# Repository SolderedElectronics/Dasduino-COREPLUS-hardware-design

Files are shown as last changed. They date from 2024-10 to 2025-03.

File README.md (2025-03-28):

# Dasduino COREPLUS Hardware Design

## About the Product

| Dasduino COREPLUS Image |
| :----------------------------------------------------------: |
| [Buy Dasduino COREPLUS](https://www.solde.red/333268) |

The soldered version of the ATmega2560 microcontroller board has arrived! It is designed for enthusiasts and professionals in the field of electronics and DIY projects. The heart of the board, the ATmega2560, is a powerful 8-bit microcontroller that offers enough processing power for demanding applications. The board comes with a large number of digital and analog inputs/outputs, allowing users to connect various sensors and actuators. The ATmega2560 contains a significant amount of Flash memory, SRAM, and EEPROM, which is sufficient for complex applications and data storage. The USB interface allows for easy programming and communication with a computer. It enables communication with various peripheral devices and modules using the qwiic system for simple connectivity. The board is compatible with popular development environments, such as Arduino IDE, which facilitates the development and implementation of projects.

This board is ideal for creating complex and versatile electronic projects, such as automatic systems, smart devices, robotics, and many others.

---

## Repository Contents

This repository contains all design files for Dasduino COREPLUS, organized as follows:

- **`CAD` folder**: Contains KiCAD design files, including:
  - Schematics
  - PCB layout
  - Panel PCB layout
  - Source 3D files in Fusion360, if any
  - All files are sorted by version with a detailed change log.
- **`OUTPUTS` folder**: Includes all production-ready files, such as:
  - Bill of Materials (BOM) and interactive BOM (iBOM)
  - PDF versions of schematics
  - 3D `.step` file of the board
  - 3D-printable models
  - Gerber files for PCB manufacturing
  - Image of the pinout of the board
  - Product image
  - Compliance, legal and generic sales documents

Refer to the `Change Log` in the CAD folder for details about updates between versions.

---

## Learn More About the Product

Beyond the repository, explore the following resources:

### Soldered Verify

Soldered Verify Logo

The **Soldered Verify** system ensures every board you purchase from Soldered is fully functional. It also provides access to exclusive test data for your product. To get started, find the unique Soldered Verify ID on your product's packaging and enter the ID on the [Soldered Verify page](https://soldered.com/verify/) to access test results and additional product details.

### Soldered Community

soldered-verify-logo

Soldered Community is your go-to place for technical support. Our engineers track and answer all questions posted there, and it’s a great space for the maker community. Get answers to your questions and solutions for your challenges at [Soldered Community](https://soldered.com/community).

### solde.red

solde.red is an ultimate URL shortener and information hub. Access it by typing solde.red/ followed by your product SKU, e.g., [solde.red/333000](https://solde.red/333000), to find getting-started guides, datasheets, open-source hardware and software files, certifications, images, pinouts, and more. Read more about the shortener [here](https://solde.red/info/).

---

## Contributing

Contributions are welcome! Here’s how you can get involved:

- Submit pull requests to enhance the design or fix issues.
- Report bugs or problems by opening an issue.

We encourage community collaboration to make this product even better.

---

## About Soldered

soldered-logo

[Soldered for Makers](https://soldered.com) specializes in designing and manufacturing electronic products tailored for enthusiasts, ranging from hobbyists to professionals. Our portfolio includes electronic boards, sensors, and actuators that are widely utilized in fields such as microelectronics, mechatronics, robotics, programming, and IoT. Every product we offer is designed in-house and built upon open-source hardware and software platforms. Proudly certified and manufactured within the European Union, our catalog likely includes the product you need for your project.

We complement these products with comprehensive tutorials and manuals, product descriptions, schematics, programming codes, and project examples. Our round-the-clock [customer and technical support](https://soldered.com/community) is available for all our products, irrespective of the sales channel. Soldered’s success and services reflect our maker community’s unwavering [trust](https://www.trustpilot.com/review/soldered.com), for which we are deeply grateful. Join our community and create using Soldered products.

---

## License

All Soldered open-source hardware (OSH) is under The TAPR Open Hardware License. Read more in the LICENSE file located in this repository.

**Disclaimer:**

No warranty - all designs in this repository are distributed in the hope that they will be useful, but without any warranty. They are provided "AS IS", therefore without warranty of any kind, either expressed or implied. The entire quality and performance of what you do with the contents of this repository are your responsibility. In no event Soldered Electronics will be liable for your damages, or losses, including any general, special, incidental, or consequential damage arising out of the use or inability to use the contents of this repository. 

---

## Have fun!

Thank you for your support from your fellow makers at Soldered Electronics.

Happy Making!

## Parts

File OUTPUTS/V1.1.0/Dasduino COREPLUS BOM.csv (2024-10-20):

Id | Designator | Package | Quantity | Designation | Supplier and ref
1 | JP6,JP5 | SMD_JUMPER_3_PAD_TRACE | 2 | SMD_JUMPER_3_PAD_TRACE
2 | R19,R10,R21,R20,R22 | 0603R | 5 | 10k
3 | R2,R1,R5 | 0603R | 3 | 1k
4 | R3,R17,R4,R12 | 0402R | 4 | 2k2
5 | F1 | 1206FUSE | 1 | 1206FUSE-500mA
6 | C26,C1,C24,C21,C25,C10,C22,C18,C23,C2,C19,C4,C11,C20 | 0603C | 14 | 100n
7 | U5 | SOT-363 | 1 | NMOS-DUAL
8 | JP4 | SMD_JUMPER | 1 | SMD_JUMPER
9 | C5,C3,C7,C9,C8 | 0603C | 5 | 2u2
10 | D2,D6 | 0402LED | 2 | orange
11 | JP2,JP3,JP1 | SMD-JUMPER-CONNECTED_TRACE_SOLDERMASK | 3 | SMD-JUMPER-CONNECTED_TRACE_SOLDERMASK
12 | C14,C15,C12,C13 | 1206C | 4 | 10u
13 | H3,H4,H1,H2 | HOLE_3.2mm | 4 | HOLE_3.2mm
14 | R7,R8 | 0603R | 2 | 5k1
15 | U2 | TPS7A2633DRVR | 1 | TPS7A2633DRVR
16 | R18 | 0603R | 1 | 100
17 | D4 | WS2812B-2020 | 1 | WS2812B-2020
18 | D3 | 0402LED | 1 | purple
19 | U4 | TQFP-100 | 1 | ATMEGA2560-16AU
20 | U1 | SOP-16 | 1 | CH340C
21 | K1 | easyC-connector | 1 | easyC-SMD
22 | K8 | HYC77-TF09-200 | 1 | HYC77-TF09-200
23 | D1 | 0402LED | 1 | blue
24 | R16,R14,R15,R13,R9 | 0603R | 5 | 100k
25 | Q1,Q2 | SOT-23-3 | 2 | PMOS
26 | C16,C17 | 0603C | 2 | 22p
27 | U6 | TXB0104QPWRQ1 | 1 | TXB0104QPWRQ1
28 | D5 | 0402LED | 1 | red
29 | SW1,SW2 | YTSA007A0151803B | 2 | YTSA007A0151803B
30 | C6 | 0603C | 1 | 270p
31 | K3 | JST-2pin-SMD | 1 | JST-2pin-SMD
32 | TP2,TP1 | Test_Point_SMD_0.8mm | 2 | Test_Point_SMD_0.8mm
33 | U3 | TP4056M-MSOP8 | 1 | TP4056M
34 | R11 | 0603R | 1 | 3k
35 | R6 | 0402R | 1 | 330
36 | D7 | SOD-323 | 1 | BAT20J
37 | X1 | CRYSTAL_3225__4_PAD | 1 | 16MHz
38 | K2 | U262-161N-4BVC11 | 1 | U262-161N-4BVC11
39 | K6 | HEADER_MALE_20x1 | 1 | HEADER_MALE_20X1
40 | K4,K5 | HEADER_MALE_40X1 | 2 | HEADER_MALE_40X1

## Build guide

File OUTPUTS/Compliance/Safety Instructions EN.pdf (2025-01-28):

PLEASE RETAIN THIS INFORMATION FOR FUTURE REFERENCE.

BEFORE USING THIS PRODUCT, READ ALL INSTRUCTION IN THIS DOCUMENT.

Product name: Dasduino COREPLUS (ATmega2560)
Getting started: To get started, please visit www.soldered.com

## WARNINGS

- This product should not be covered and should be operated in well ventilated enviroment.
- The product should be placed on a stable, flat, non-conductive surface and should not be contacted by conductive items.
- Connection of other devices may affect compliance or result in damage to the unit, and invalidate the warranty.
- Where peripherals are connected that do not include the cable or connector, the cable or connector used must offer adequate insulation and operation in order that the requirements of the relevant performance and safety requirements are met.
- There is a danger of explosion if the battery is incorrectly placed.
- The product should not be used outside of its specified working range.

## INSTRUCTIONS FOR SAFE USE

To avoid malfunction or damage to your device, please observe the following:
- Do not expose it to water, moisture or place on a conductive surface when turned on. Do not handle the unit with wet hands.
- Do not expose it to heat from any source; the product is designed to be used at normal ambient room temperatures. The product is intended to be used inside.
- Take care when handling to avoid mechanical or electrical damage to any part of the unit. Avoid handling the unit while it's powered. Use ESD protection.
- Use only supplied cable (or the cable of the same or higher quality) with the unit.

## COMPLIANCE INFORMATION

The product complies with the relevant provision of the RoHS Directive for the European Union. In common with all Electrical and Electronic Equipment (EEE), the product should not be disposed household waste.

ELECTROMAGNETIC COMPABILITY AND OPERATION

- The product is in conformity with the protection requirements of EU Council Directive 2014/30/EU on the laws of the Member States relating of electromagnetic compability, and Electromagnetic Compability Regulations 2016 of the UK.
- WARNING: Please do not alter the design of this product, doing so may void your ability to use the product freely, this includes altering the frequency at which product operates.

### Regulatory Compliance and Important Safety Information

Soldered Electronics d.o.o., Vinkovačka cesta 68, 31000 Osijek, Croatia. VAT ID: HR83200237288

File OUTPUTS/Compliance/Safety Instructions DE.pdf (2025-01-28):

BITTE BEWAHREN SIE DIESE INFORMATIONEN ZUR SPÄTEREN VERWENDUNG AUF.
LESEN SIE VOR DER VERWENDUNG DIESES PRODUKTS ALLE ANWEISUNGEN IN DOKUMENT. Produktname: Dasduino COREPLUS (ATmega2560)
Die ersten Schritte:Besuchen Sie www.soldered.com, um loszulegen.

## WARNUNGEN

- Dieses Produkt sollte nicht abgedeckt werden und in einer gut belüfteten Umgebung betrieben werden.
- Das Produkt sollte auf einer stabilen, flachen, nicht leitenden Oberfläche aufgestellt werden und nicht mit leitenden Gegenständen in Berührung kommen.
- Der Anschluss anderer Geräte kann die Konformität beeinträchtigen oder zu Schäden am Gerät führen und zum Erlöschen der Garantie führen.
- Wenn Peripheriegeräte angeschlossen werden, die nicht das Kabel oder den Stecker enthalten, muss das verwendete Kabel oder muss das verwendete Kabel bzw. der verwendete Steckverbinder eine angemessene Isolierung und Funktion aufweisen, damit die Anforderungen die einschlägigen Leistungs- und Sicherheitsanforderungen erfüllt werden.
- Es besteht Explosionsgefahr, wenn die Batterie falsch eingesetzt wird.
- Das Produkt sollte nicht außerhalb des angegebenen Arbeitsbereichs verwendet werden.

## HINWEISE ZUR SICHEREN ANWENDUNG

Um Fehlfunktionen oder Schäden an Ihrem Gerät zu vermeiden, beachten Sie bitte die folgenden Hinweise:
- Setzen Sie das Gerät nicht Wasser oder Feuchtigkeit aus und stellen Sie es nicht auf eine
leitende Oberfläche, wenn es eingeschaltet ist. Das Gerät nicht mit nassen Händen anfassen.
- Setzen Sie es keiner Wärmequelle aus; das Produkt ist für die Verwendung bei normalen Raumtemperaturen ausgelegt. Das Produkt ist für die Verwendung in Innenräumen vorgesehen.
- Seien Sie bei der Handhabung vorsichtig, um mechanische oder elektrische Schäden an Teilen des Geräts zu vermeiden. Fassen Sie das Gerät nicht an, wenn es unter Spannung steht. Verwenden Sie einen ESD-Schutz.
- Verwenden Sie nur das mitgelieferte Kabel (oder ein gleich- oder höherwertiges Kabel)
mit dem Gerät.

## COMPLIANCE-INFORMATIONEN

Das Produkt entspricht den entsprechenden Bestimmungen der RoHS-Richtlinie für die Europäische Union. Wie alle elektrischen und elektronischen Geräte (EEE), sollte das Produkt nicht über den Hausmüll entsorgt werden.
ELEKTROMAGNETISCHE VERTRÄGLICHKEIT UND BETRIEB
- Das Produkt entspricht den Schutzanforderungen der Richtlinie des EU-Rates 2014/30/EU über die Rechtsvorschriften der Mitgliedstaaten zur elektromagnetischen Verträglichkeit und den Elektromagnetische Verträglichkeitsverordnung 2016 des Vereinigten Königreichs.
- WARNUNG: Bitte verändern Sie nicht das Design dieses Produkts, da dies dazu führen kann, dass Sie das Produkt nicht mehr uneingeschränkt nutzen können.
Dies gilt auch für die Änderung der Frequenz, mit der das Produkt arbeitet.

## Einhaltung gesetzlicher Vorschriften und wichtige

Soldered Electronics d.o.o., Vinkovačka cesta 68, 31000 Osijek, Croatia. VAT ID: HR83200237288

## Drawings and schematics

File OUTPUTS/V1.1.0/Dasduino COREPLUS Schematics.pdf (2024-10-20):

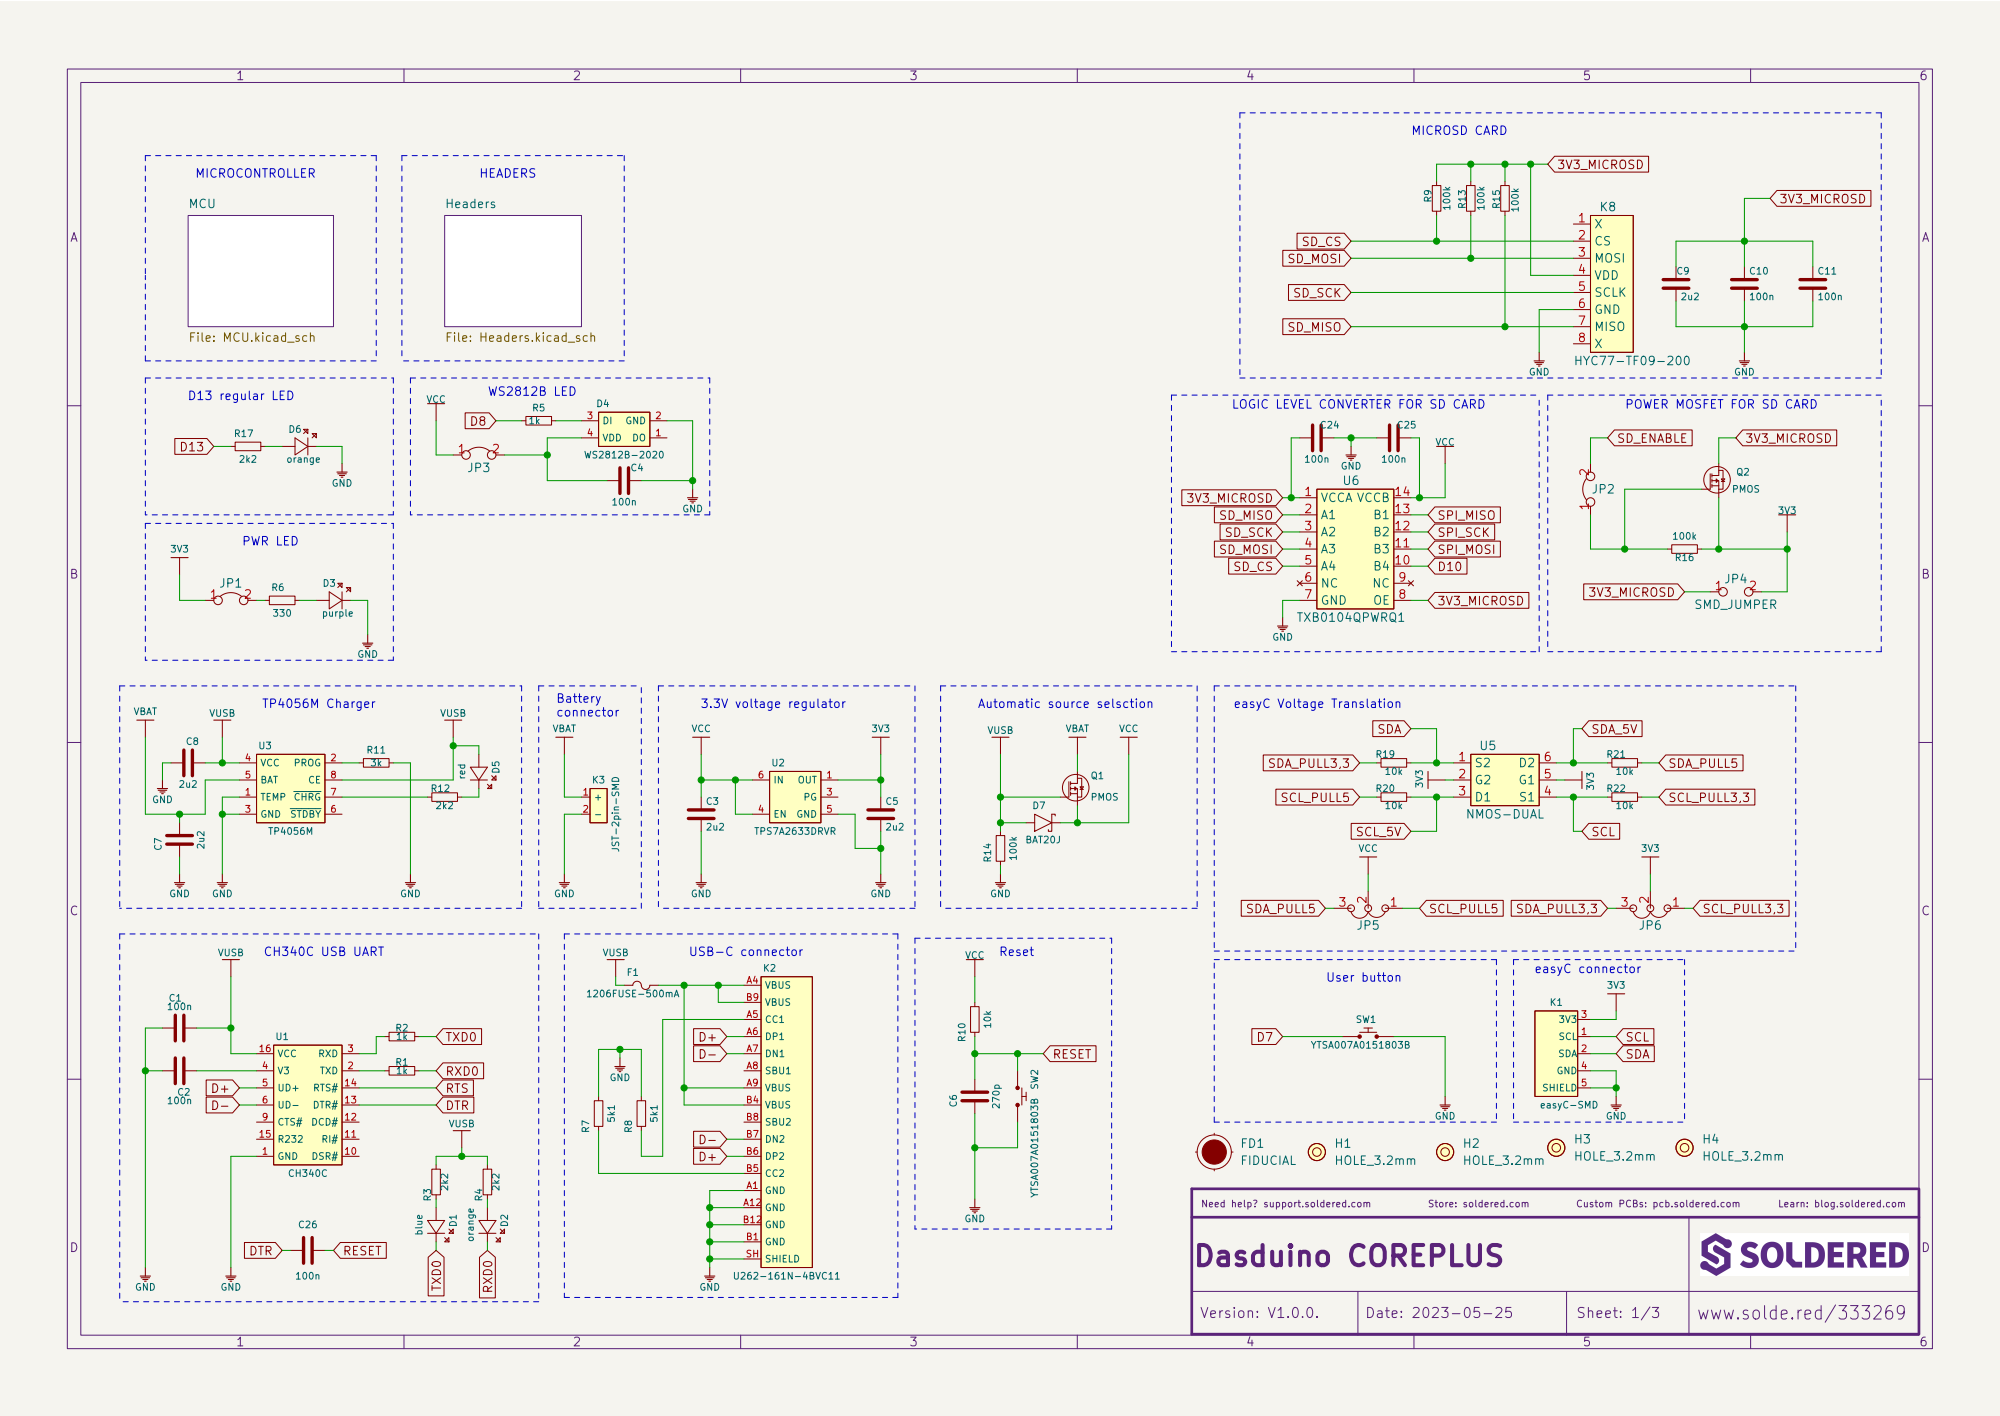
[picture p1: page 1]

Headers File: Headers.kicad_sch MCU

Learn: blog.soldered.com

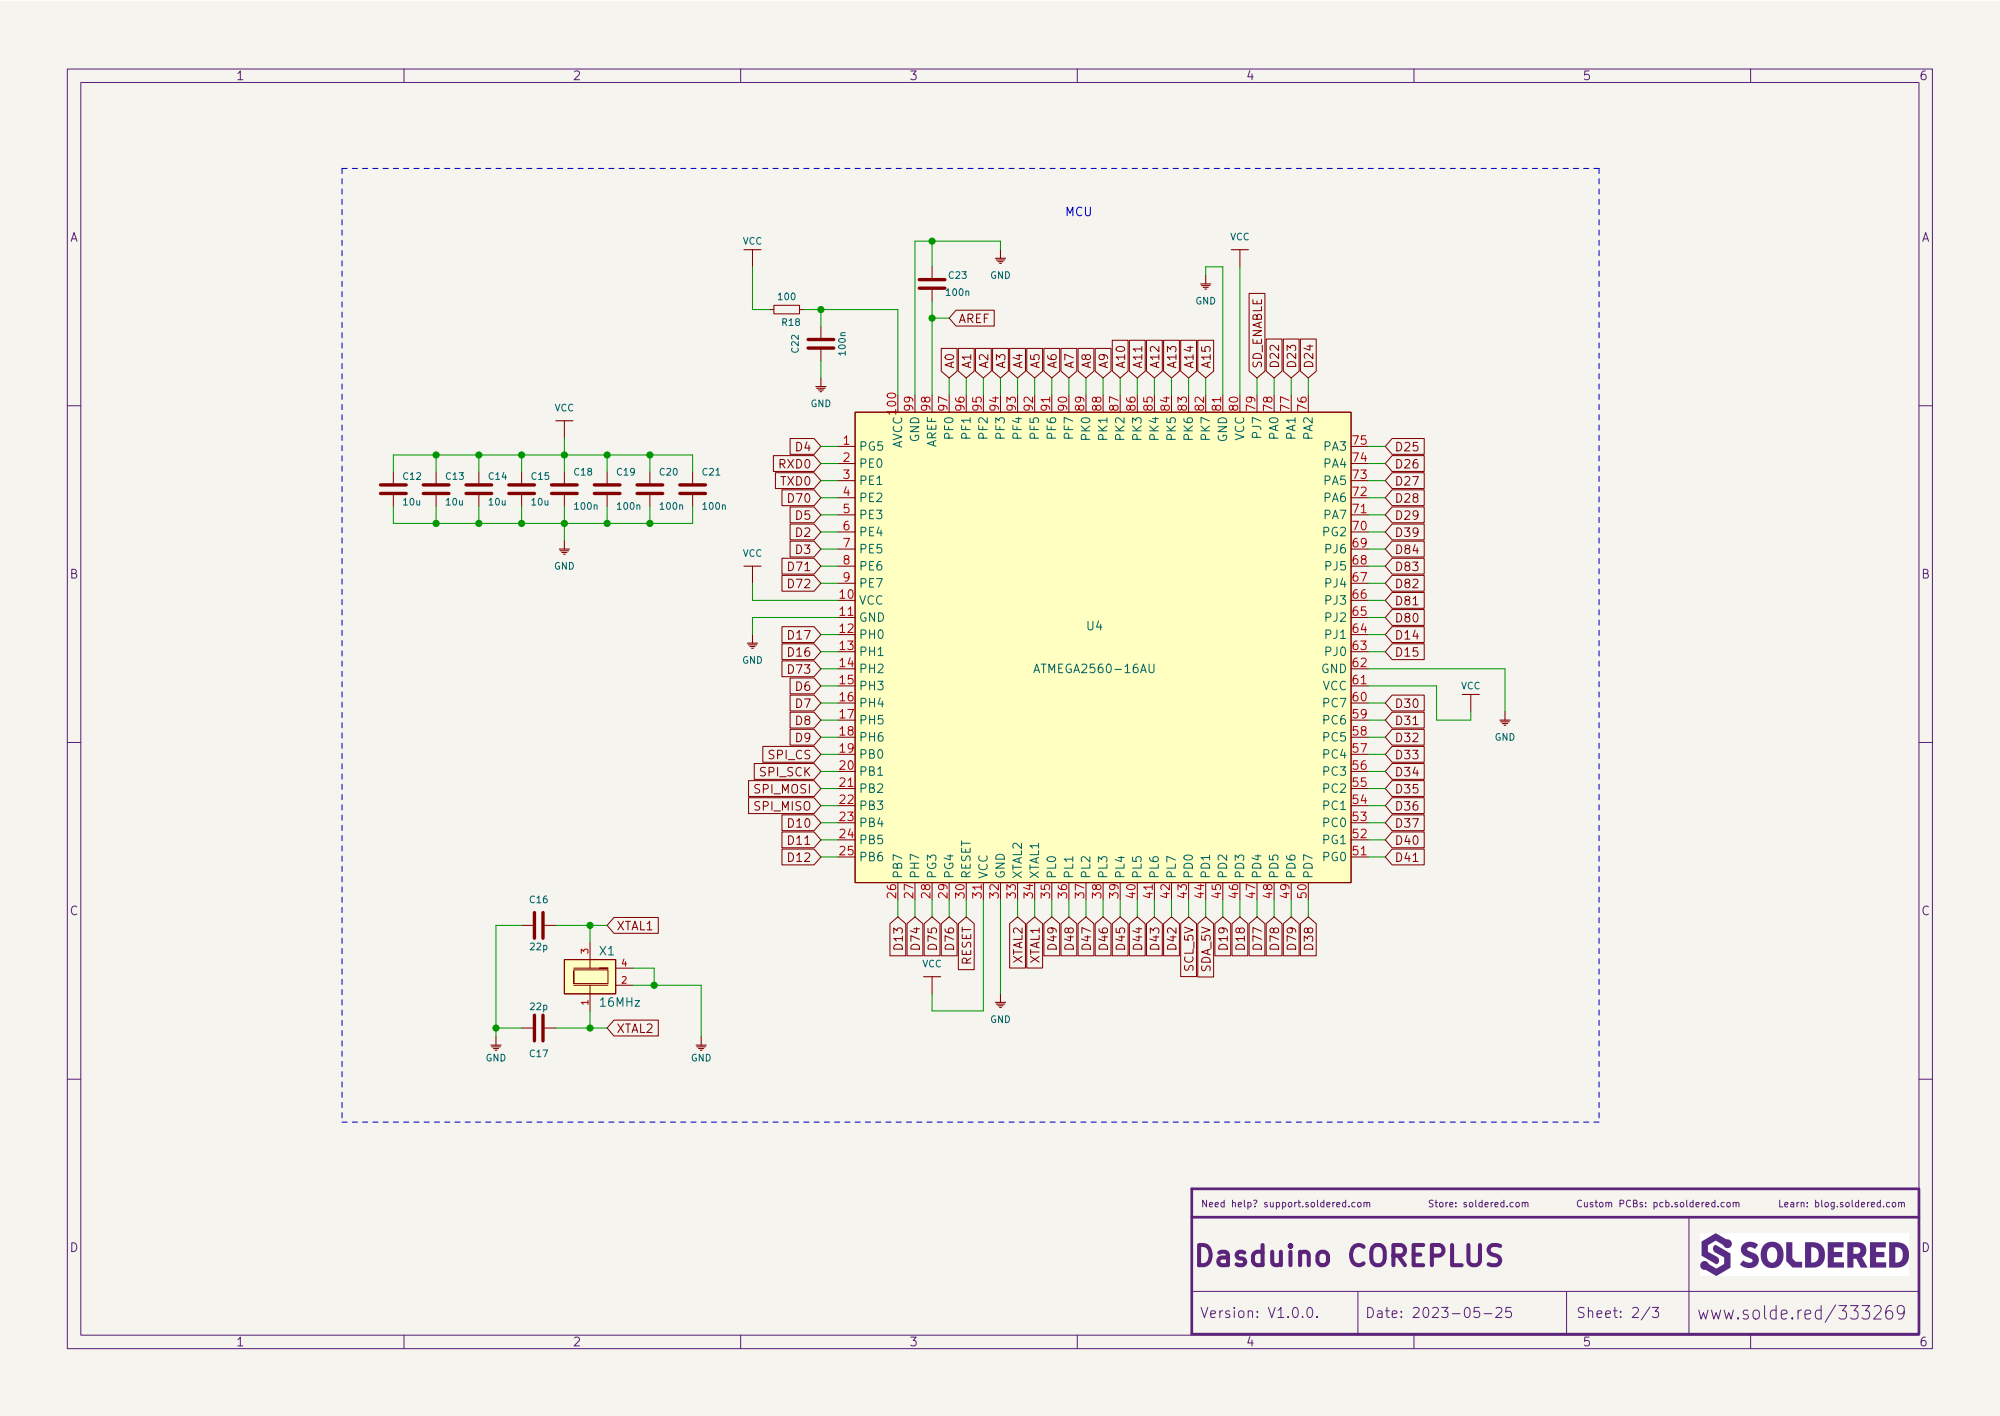
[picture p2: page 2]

Learn: blog.soldered.com

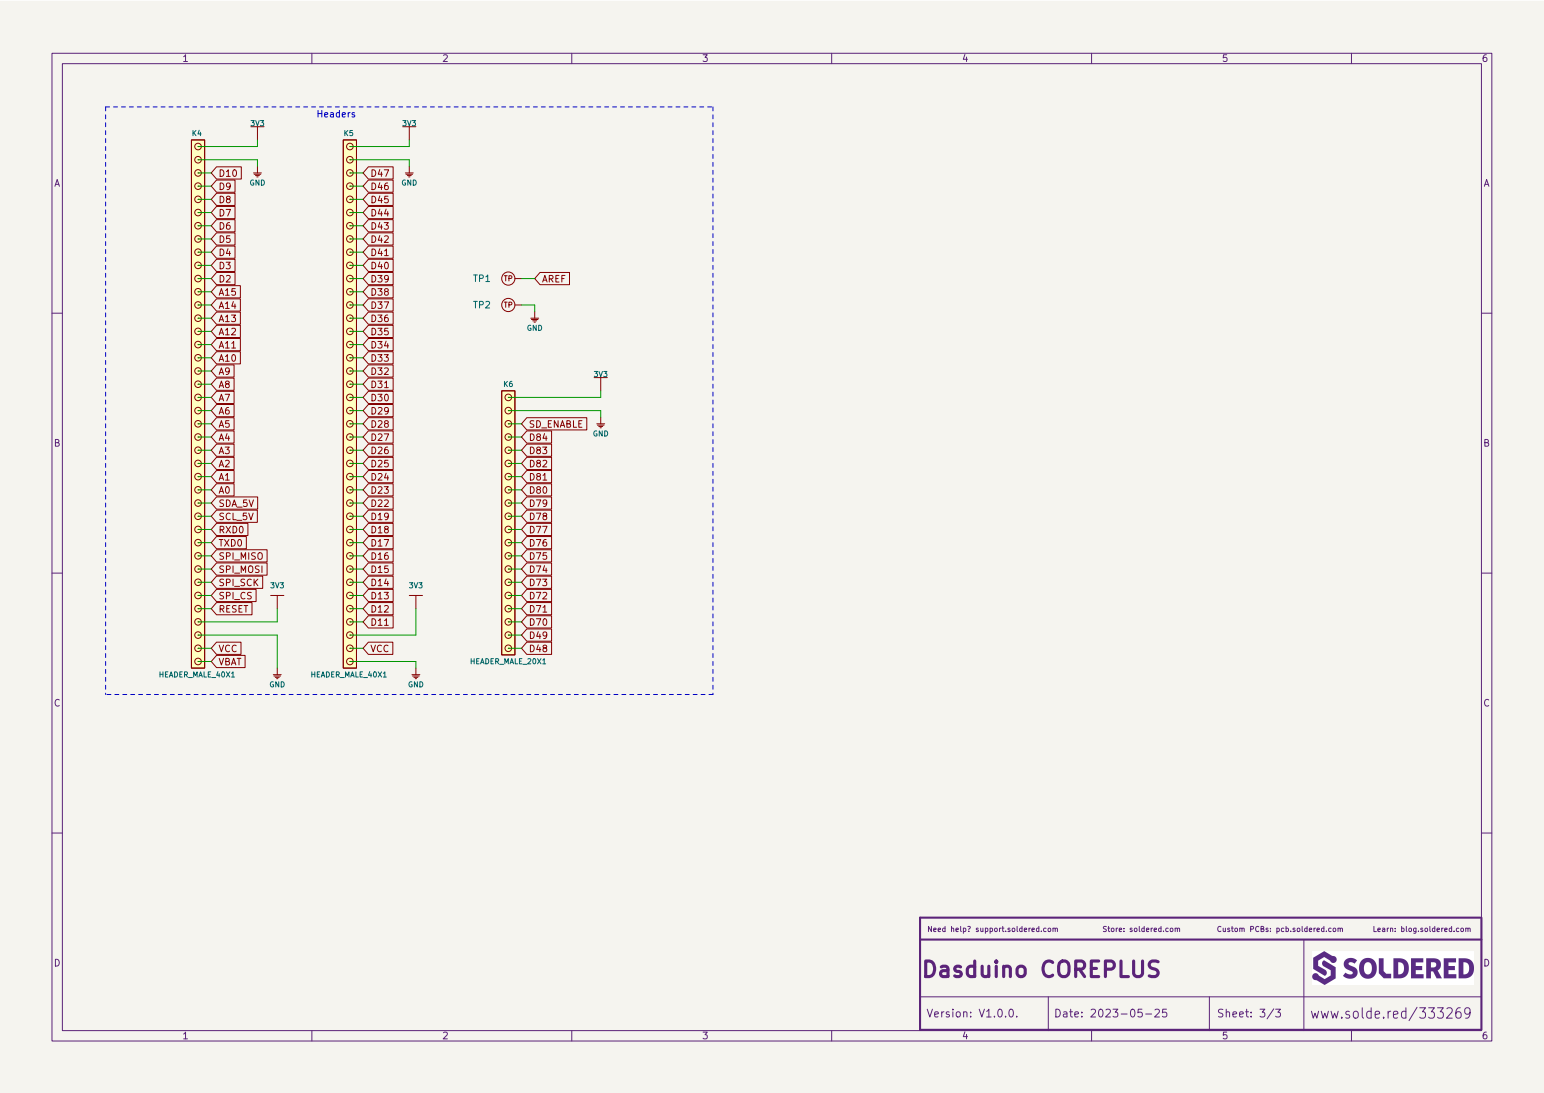
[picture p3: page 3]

Learn: blog.soldered.com

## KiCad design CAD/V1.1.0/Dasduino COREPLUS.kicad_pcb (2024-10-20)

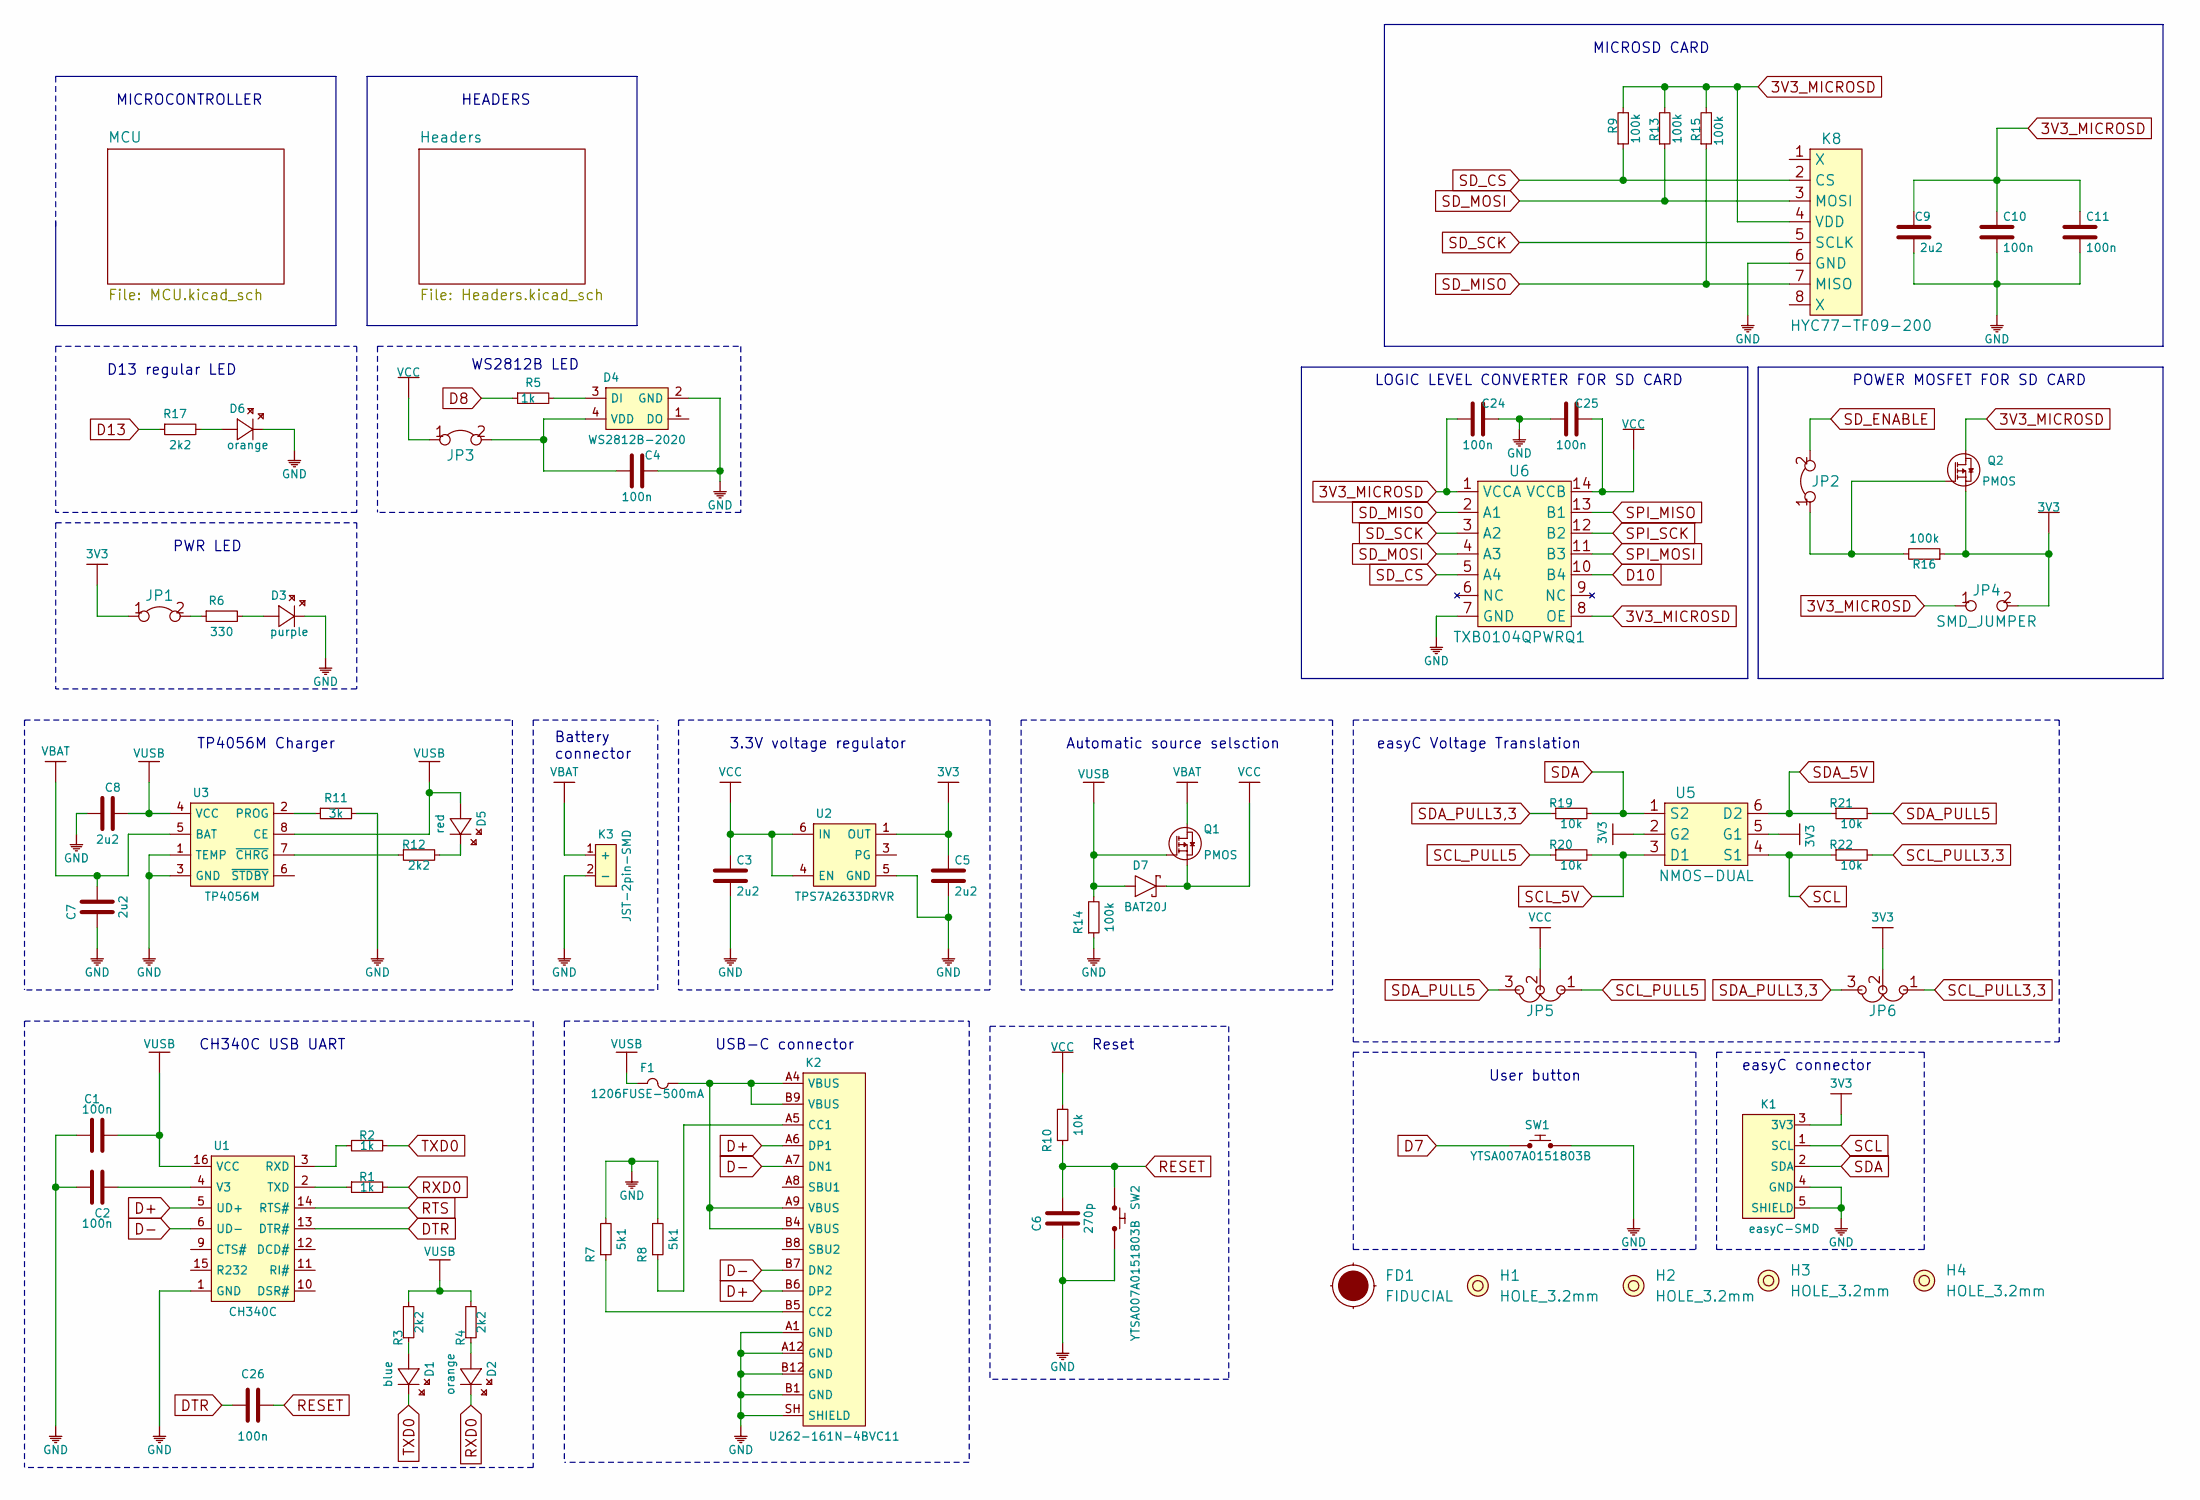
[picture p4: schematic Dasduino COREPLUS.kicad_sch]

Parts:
C1, C2, C4, C10, C11, C24, C25, C26: 100n; 0603C
C3, C5, C7, C8, C9: 2u2; 0603C
C6: 270p; 0603C
D1: blue; 0402LED
D2, D6: orange; 0402LED
D3: purple; 0402LED
D4: WS2812B-2020
D5: red; 0402LED
D7: BAT20J; SOD-323
F1: 1206FUSE-500mA; 1206FUSE
FD1: FIDUCIAL; FIDUCIAL_23
H1, H2, H3, H4: HOLE_3.2mm
JP1, JP2, JP3: SMD-JUMPER-CONNECTED_TRACE_SOLDERMASK
JP4: SMD_JUMPER
JP5, JP6: SMD_JUMPER_3_PAD_TRACE
K1: easyC-SMD; easyC-connector
K2: U262-161N-4BVC11
K3: JST-2pin-SMD
K8: HYC77-TF09-200
Q1, Q2: PMOS; SOT-23-3
R1, R2, R5: 1k; 0603R
R3, R4, R12, R17: 2k2; 0402R
R6: 330; 0402R
R7, R8: 5k1; 0603R
R9, R13, R14, R15, R16: 100k; 0603R
R10, R19, R20, R21, R22: 10k; 0603R
R11: 3k; 0603R
SW1, SW2: YTSA007A0151803B
U1: CH340C; SOP-16
U2: TPS7A2633DRVR
U3: TP4056M; TP4056M-MSOP8
U5: NMOS-DUAL; SOT-363
U6: TXB0104QPWRQ1

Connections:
3V3: C5.2, JP1.1, JP4.2, JP6.2, K1.3 (3V3), Q2.2 (S), R16.1, U2.1 (OUT), U5.2 (G2), U5.5 (G1); also elsewhere on the board
3V3_MICROSD: C9.2, C10.2, C11.2, C24.1, JP4.1, K8.4 (VDD), Q2.3 (D), R9.2, R13.2, R15.2, U6.1 (VCCA), U6.8 (OE)
D7: SW1.1; also elsewhere on the board
D8: R5.1; also elsewhere on the board
D10: U6.10 (B4); also elsewhere on the board
D13: R17.1; also elsewhere on the board
D+: K2.A6 (DP1), K2.B6 (DP2), U1.5 (UD+)
D-: K2.A7 (DN1), K2.B7 (DN2), U1.6 (UD-)
DTR: C26.2, U1.13 (DTR#)
GND: C1.1, C2.2, C3.1, C4.2, C5.1, C6.1, C7.1, C8.2, C9.1, C10.1, C11.1, C24.2, C25.1, D3.2 (K), D4.2 (GND), D6.2 (K), K1.4 (GND), K1.5 (SHIELD), K2.A1 (GND), K2.A12 (GND), K2.B1 (GND), K2.B12 (GND), K2.SH (SHIELD), K3.2 (-), K8.6 (GND), R7.2, R8.2, R11.2, R14.1, SW1.2, SW2.2, U1.1 (GND), U2.5 (GND), U3.1 (TEMP), U3.3 (GND), U6.7 (GND); also elsewhere on the board
unnamed: C2.1, U1.4 (V3)
unnamed: C4.1, D4.4 (VDD), JP3.2
unnamed: D1.1 (A), R3.1
unnamed: D2.1 (A), R4.1
unnamed: D3.1 (A), R6.2
unnamed: D4.3 (DI), R5.2
unnamed: D5.2 (K), R12.2
unnamed: D6.1 (A), R17.2
unnamed: F1.2, K2.A4 (VBUS), K2.A9 (VBUS), K2.B4 (VBUS), K2.B9 (VBUS)
unnamed: JP1.2, R6.1
unnamed: JP2.1, Q2.1 (G), R16.2
unnamed: K2.A5 (CC1), R8.1
unnamed: K2.B5 (CC2), R7.1
unnamed: R1.1, U1.2 (TXD)
unnamed: R2.1, U1.3 (RXD)
unnamed: R11.1, U3.2 (PROG)
unnamed: R12.1, U3.7 (~CHRG)
RESET: C6.2, C26.1, R10.1, SW2.1; also elsewhere on the board
RTS: U1.14 (RTS#)
RXD0: D2.2 (K), R1.2; also elsewhere on the board
SCL: K1.1 (SCL), R22.1, U5.4 (S1)
SCL_5V: R20.2, U5.3 (D1); also elsewhere on the board
SCL_PULL3,3: JP6.1, R22.2
SCL_PULL5: JP5.1, R20.1
SDA: K1.2 (SDA), R19.2, U5.1 (S2)
SDA_5V: R21.1, U5.6 (D2); also elsewhere on the board
SDA_PULL3,3: JP6.3, R19.1
SDA_PULL5: JP5.3, R21.2
SD_CS: K8.2 (CS), R9.1, U6.5 (A4)
SD_ENABLE: JP2.2; also elsewhere on the board
SD_MISO: K8.7 (MISO), R15.1, U6.2 (A1)
SD_MOSI: K8.3 (MOSI), R13.1, U6.4 (A3)
SD_SCK: K8.5 (SCLK), U6.3 (A2)
SPI_MISO: U6.13 (B1); also elsewhere on the board
SPI_MOSI: U6.11 (B3); also elsewhere on the board
SPI_SCK: U6.12 (B2); also elsewhere on the board
TXD0: D1.2 (K), R2.2; also elsewhere on the board
VBAT: C7.2, K3.1 (+), Q1.3 (D), U3.5 (BAT); also elsewhere on the board
VCC: C3.2, C25.2, D7.2 (C), JP3.1, JP5.2, Q1.2 (S), R10.2, U2.4 (EN), U2.6 (IN), U6.14 (VCCB); also elsewhere on the board
VUSB: C1.2, C8.1, D5.1 (A), D7.1 (A), F1.1, Q1.1 (G), R3.2, R4.2, R14.2, U1.16 (VCC), U3.4 (VCC), U3.8 (CE)

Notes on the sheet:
MICROSD CARD
TP4056M Charger
PWR LED
easyC Voltage Translation
LOGIC LEVEL CONVERTER FOR SD CARD
3.3V voltage regulator
easyC connector
CH340C USB UART
User button
USB-C connector
WS2812B LED
MICROCONTROLLER
D13 regular LED
HEADERS
Battery connector
POWER MOSFET FOR SD CARD
Reset
Automatic source selsction

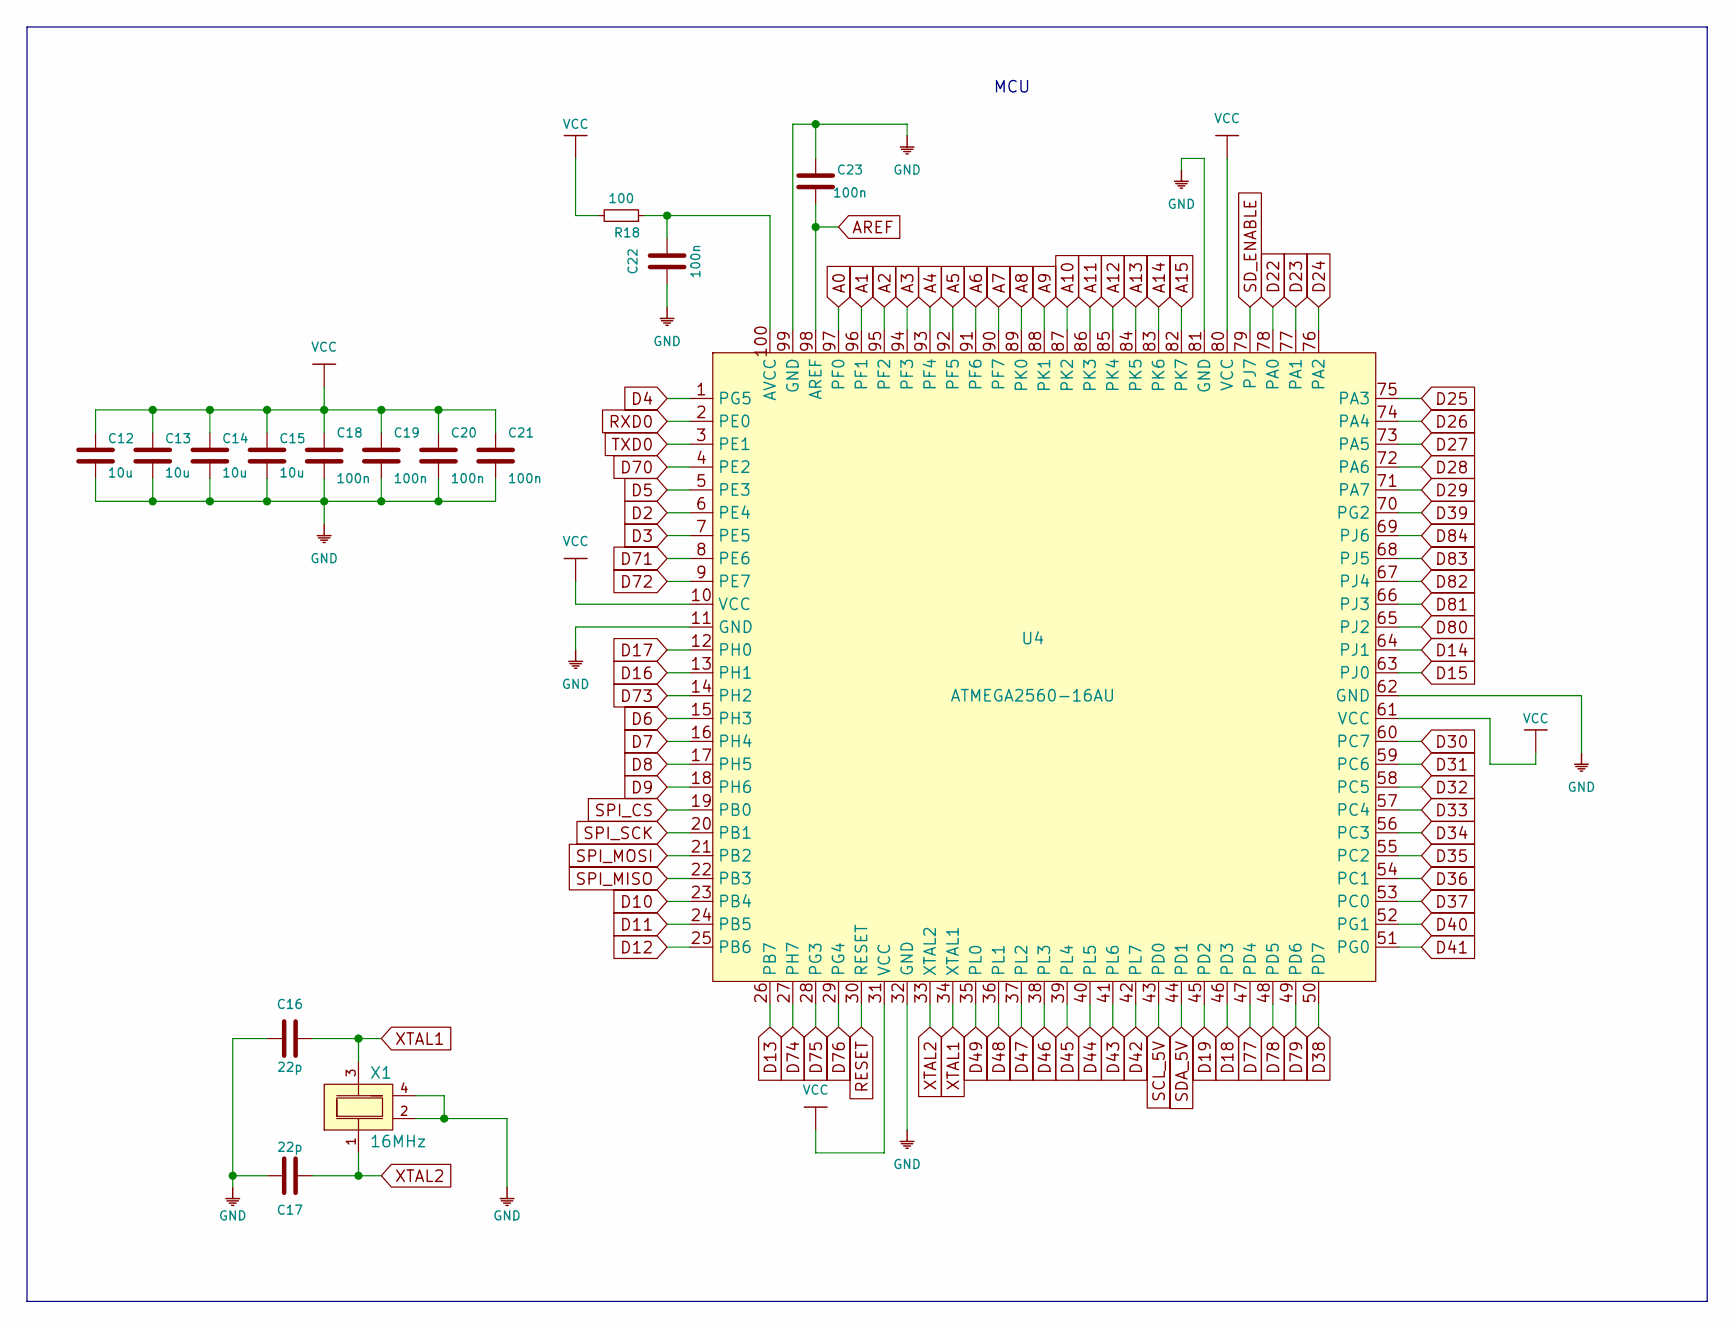
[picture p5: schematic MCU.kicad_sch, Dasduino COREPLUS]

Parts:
C12, C13, C14, C15: 10u; 1206C
C16, C17: 22p; 0603C
C18, C19, C20, C21, C22, C23: 100n; 0603C
R18: 100; 0603R
U4: ATMEGA2560-16AU; TQFP-100
X1: 16MHz; CRYSTAL_3225__4_PAD

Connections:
A0: U4.97 (PF0); also elsewhere on the board
A1: U4.96 (PF1); also elsewhere on the board
A2: U4.95 (PF2); also elsewhere on the board
A3: U4.94 (PF3); also elsewhere on the board
A4: U4.93 (PF4); also elsewhere on the board
A5: U4.92 (PF5); also elsewhere on the board
A6: U4.91 (PF6); also elsewhere on the board
A7: U4.90 (PF7); also elsewhere on the board
A8: U4.89 (PK0); also elsewhere on the board
A9: U4.88 (PK1); also elsewhere on the board
A10: U4.87 (PK2); also elsewhere on the board
A11: U4.86 (PK3); also elsewhere on the board
A12: U4.85 (PK4); also elsewhere on the board
A13: U4.84 (PK5); also elsewhere on the board
A14: U4.83 (PK6); also elsewhere on the board
A15: U4.82 (PK7); also elsewhere on the board
AREF: C23.1, U4.98 (AREF); also elsewhere on the board
D2: U4.6 (PE4); also elsewhere on the board
D3: U4.7 (PE5); also elsewhere on the board
D4: U4.1 (PG5); also elsewhere on the board
D5: U4.5 (PE3); also elsewhere on the board
D6: U4.15 (PH3); also elsewhere on the board
D7: U4.16 (PH4); also elsewhere on the board
D8: U4.17 (PH5); also elsewhere on the board
D9: U4.18 (PH6); also elsewhere on the board
D10: U4.23 (PB4); also elsewhere on the board
D11: U4.24 (PB5); also elsewhere on the board
D12: U4.25 (PB6); also elsewhere on the board
D13: U4.26 (PB7); also elsewhere on the board
D14: U4.64 (PJ1); also elsewhere on the board
D15: U4.63 (PJ0); also elsewhere on the board
D16: U4.13 (PH1); also elsewhere on the board
D17: U4.12 (PH0); also elsewhere on the board
D18: U4.46 (PD3); also elsewhere on the board
D19: U4.45 (PD2); also elsewhere on the board
D22: U4.78 (PA0); also elsewhere on the board
D23: U4.77 (PA1); also elsewhere on the board
D24: U4.76 (PA2); also elsewhere on the board
D25: U4.75 (PA3); also elsewhere on the board
D26: U4.74 (PA4); also elsewhere on the board
D27: U4.73 (PA5); also elsewhere on the board
D28: U4.72 (PA6); also elsewhere on the board
D29: U4.71 (PA7); also elsewhere on the board
D30: U4.60 (PC7); also elsewhere on the board
D31: U4.59 (PC6); also elsewhere on the board
D32: U4.58 (PC5); also elsewhere on the board
D33: U4.57 (PC4); also elsewhere on the board
D34: U4.56 (PC3); also elsewhere on the board
D35: U4.55 (PC2); also elsewhere on the board
D36: U4.54 (PC1); also elsewhere on the board
D37: U4.53 (PC0); also elsewhere on the board
D38: U4.50 (PD7); also elsewhere on the board
D39: U4.70 (PG2); also elsewhere on the board
D40: U4.52 (PG1); also elsewhere on the board
D41: U4.51 (PG0); also elsewhere on the board
D42: U4.42 (PL7); also elsewhere on the board
D43: U4.41 (PL6); also elsewhere on the board
D44: U4.40 (PL5); also elsewhere on the board
D45: U4.39 (PL4); also elsewhere on the board
D46: U4.38 (PL3); also elsewhere on the board
D47: U4.37 (PL2); also elsewhere on the board
D48: U4.36 (PL1); also elsewhere on the board
D49: U4.35 (PL0); also elsewhere on the board
D70: U4.4 (PE2); also elsewhere on the board
D71: U4.8 (PE6); also elsewhere on the board
D72: U4.9 (PE7); also elsewhere on the board
D73: U4.14 (PH2); also elsewhere on the board
D74: U4.27 (PH7); also elsewhere on the board
D75: U4.28 (PG3); also elsewhere on the board
D76: U4.29 (PG4); also elsewhere on the board
D77: U4.47 (PD4); also elsewhere on the board
D78: U4.48 (PD5); also elsewhere on the board
D79: U4.49 (PD6); also elsewhere on the board
D80: U4.65 (PJ2); also elsewhere on the board
D81: U4.66 (PJ3); also elsewhere on the board
D82: U4.67 (PJ4); also elsewhere on the board
D83: U4.68 (PJ5); also elsewhere on the board
D84: U4.69 (PJ6); also elsewhere on the board
GND: C12.1, C13.1, C14.1, C15.1, C16.1, C17.2, C18.1, C19.1, C20.1, C21.1, C22.1, C23.2, U4.11 (GND), U4.32 (GND), U4.62 (GND), U4.81 (GND), U4.99 (GND), X1.2, X1.4; also elsewhere on the board
unnamed: C22.2, R18.1, U4.100 (AVCC)
RESET: U4.30 (RESET); also elsewhere on the board
RXD0: U4.2 (PE0); also elsewhere on the board
SCL_5V: U4.43 (PD0); also elsewhere on the board
SDA_5V: U4.44 (PD1); also elsewhere on the board
SD_ENABLE: U4.79 (PJ7); also elsewhere on the board
SPI_CS: U4.19 (PB0); also elsewhere on the board
SPI_MISO: U4.22 (PB3); also elsewhere on the board
SPI_MOSI: U4.21 (PB2); also elsewhere on the board
SPI_SCK: U4.20 (PB1); also elsewhere on the board
TXD0: U4.3 (PE1); also elsewhere on the board
VCC: C12.2, C13.2, C14.2, C15.2, C18.2, C19.2, C20.2, C21.2, R18.2, U4.10 (VCC), U4.31 (VCC), U4.61 (VCC), U4.80 (VCC); also elsewhere on the board
XTAL1: C16.2, U4.34 (XTAL1), X1.3
XTAL2: C17.1, U4.33 (XTAL2), X1.1

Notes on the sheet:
MCU

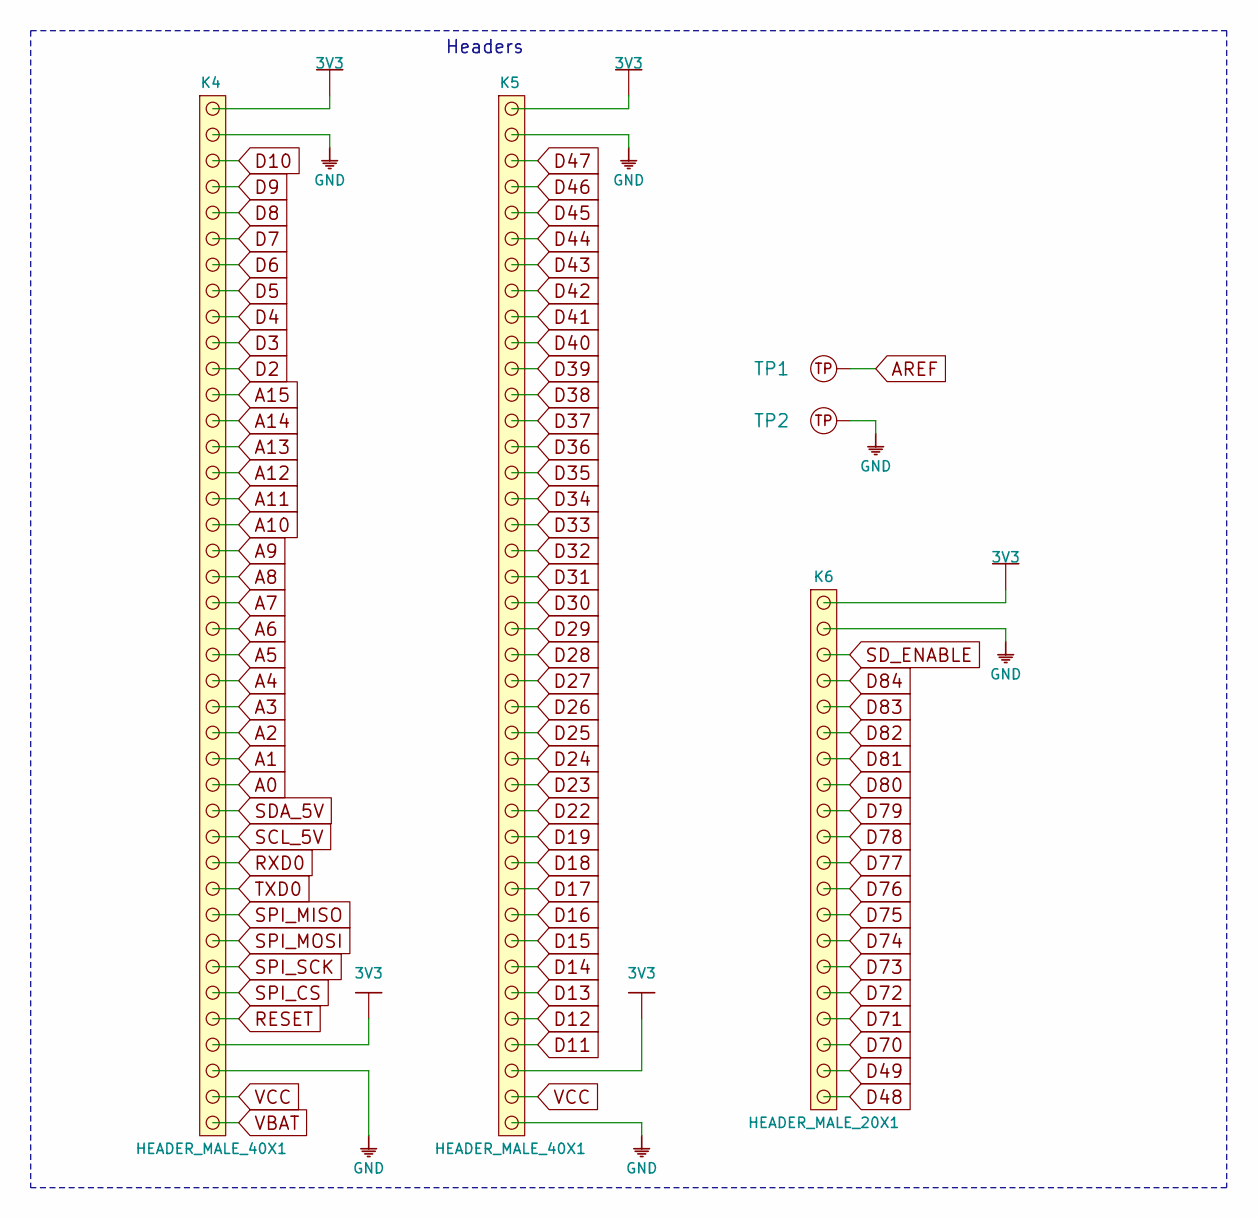
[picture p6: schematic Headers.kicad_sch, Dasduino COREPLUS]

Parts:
K4, K5: HEADER_MALE_40X1
K6: HEADER_MALE_20X1; HEADER_MALE_20x1
TP1, TP2: Test_Point_SMD_0.8mm

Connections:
3V3: K4.1, K4.37, K5.1, K5.38, K6.20; also elsewhere on the board
A0: K4.27; also elsewhere on the board
A1: K4.26; also elsewhere on the board
A2: K4.25; also elsewhere on the board
A3: K4.24; also elsewhere on the board
A4: K4.23; also elsewhere on the board
A5: K4.22; also elsewhere on the board
A6: K4.21; also elsewhere on the board
A7: K4.20; also elsewhere on the board
A8: K4.19; also elsewhere on the board
A9: K4.18; also elsewhere on the board
A10: K4.17; also elsewhere on the board
A11: K4.16; also elsewhere on the board
A12: K4.15; also elsewhere on the board
A13: K4.14; also elsewhere on the board
A14: K4.13; also elsewhere on the board
A15: K4.12; also elsewhere on the board
AREF: TP1.TP; also elsewhere on the board
D2: K4.11; also elsewhere on the board
D3: K4.10; also elsewhere on the board
D4: K4.9; also elsewhere on the board
D5: K4.8; also elsewhere on the board
D6: K4.7; also elsewhere on the board
D7: K4.6; also elsewhere on the board
D8: K4.5; also elsewhere on the board
D9: K4.4; also elsewhere on the board
D10: K4.3; also elsewhere on the board
D11: K5.37; also elsewhere on the board
D12: K5.36; also elsewhere on the board
D13: K5.35; also elsewhere on the board
D14: K5.34; also elsewhere on the board
D15: K5.33; also elsewhere on the board
D16: K5.32; also elsewhere on the board
D17: K5.31; also elsewhere on the board
D18: K5.30; also elsewhere on the board
D19: K5.29; also elsewhere on the board
D22: K5.28; also elsewhere on the board
D23: K5.27; also elsewhere on the board
D24: K5.26; also elsewhere on the board
D25: K5.25; also elsewhere on the board
D26: K5.24; also elsewhere on the board
D27: K5.23; also elsewhere on the board
D28: K5.22; also elsewhere on the board
D29: K5.21; also elsewhere on the board
D30: K5.20; also elsewhere on the board
D31: K5.19; also elsewhere on the board
D32: K5.18; also elsewhere on the board
D33: K5.17; also elsewhere on the board
D34: K5.16; also elsewhere on the board
D35: K5.15; also elsewhere on the board
D36: K5.14; also elsewhere on the board
D37: K5.13; also elsewhere on the board
D38: K5.12; also elsewhere on the board
D39: K5.11; also elsewhere on the board
D40: K5.10; also elsewhere on the board
D41: K5.9; also elsewhere on the board
D42: K5.8; also elsewhere on the board
D43: K5.7; also elsewhere on the board
D44: K5.6; also elsewhere on the board
D45: K5.5; also elsewhere on the board
D46: K5.4; also elsewhere on the board
D47: K5.3; also elsewhere on the board
D48: K6.1; also elsewhere on the board
D49: K6.2; also elsewhere on the board
D70: K6.3; also elsewhere on the board
D71: K6.4; also elsewhere on the board
D72: K6.5; also elsewhere on the board
D73: K6.6; also elsewhere on the board
D74: K6.7; also elsewhere on the board
D75: K6.8; also elsewhere on the board
D76: K6.9; also elsewhere on the board
D77: K6.10; also elsewhere on the board
D78: K6.11; also elsewhere on the board
D79: K6.12; also elsewhere on the board
D80: K6.13; also elsewhere on the board
D81: K6.14; also elsewhere on the board
D82: K6.15; also elsewhere on the board
D83: K6.16; also elsewhere on the board
D84: K6.17; also elsewhere on the board
GND: K4.2, K4.38, K5.2, K5.40, K6.19, TP2.TP; also elsewhere on the board
RESET: K4.36; also elsewhere on the board
RXD0: K4.30; also elsewhere on the board
SCL_5V: K4.29; also elsewhere on the board
SDA_5V: K4.28; also elsewhere on the board
SD_ENABLE: K6.18; also elsewhere on the board
SPI_CS: K4.35; also elsewhere on the board
SPI_MISO: K4.32; also elsewhere on the board
SPI_MOSI: K4.33; also elsewhere on the board
SPI_SCK: K4.34; also elsewhere on the board
TXD0: K4.31; also elsewhere on the board
VBAT: K4.40; also elsewhere on the board
VCC: K4.39, K5.39; also elsewhere on the board

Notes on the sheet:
Headers

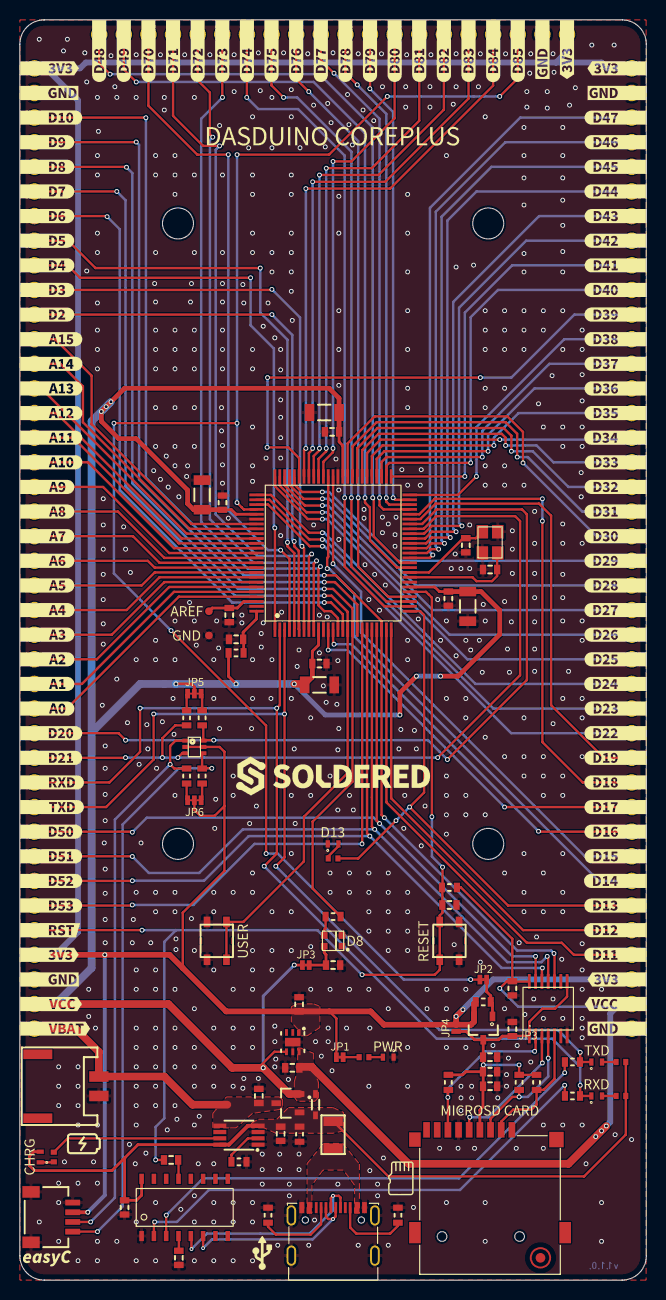
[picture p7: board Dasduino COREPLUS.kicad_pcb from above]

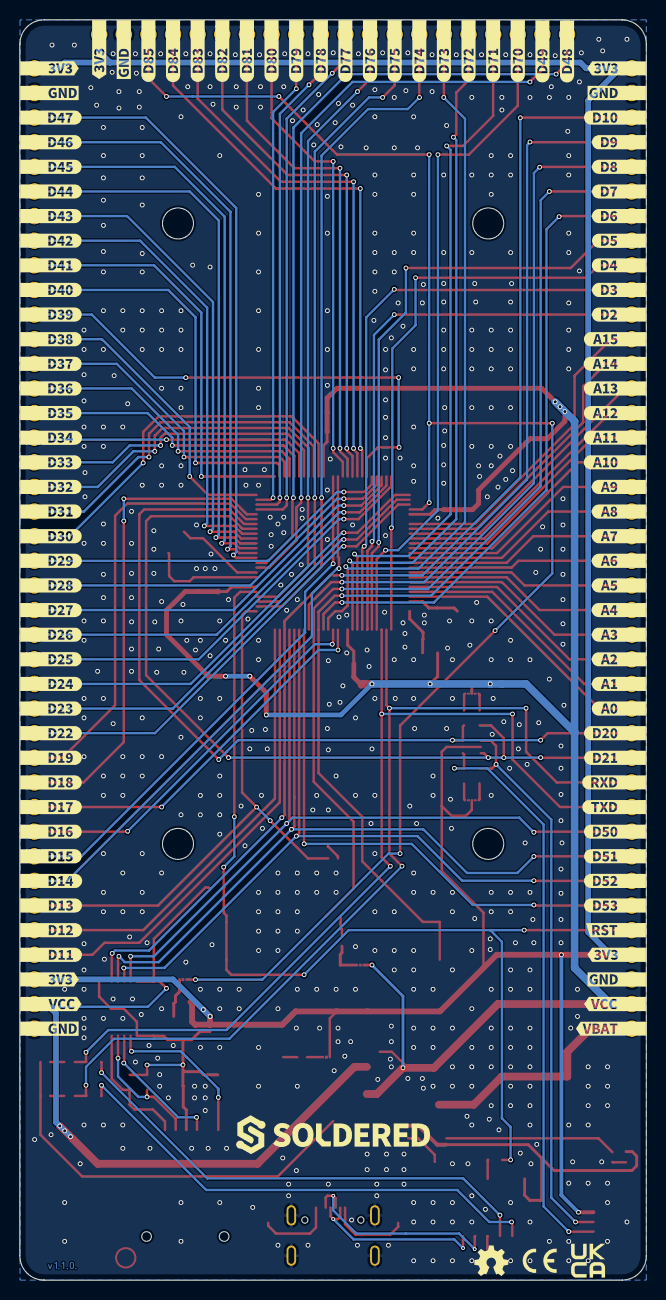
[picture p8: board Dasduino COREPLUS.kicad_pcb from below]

Board: 2 copper layers, 64.6 x 130.0 mm, 307 parts (104 on the bottom side), 127 nets.

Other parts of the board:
Ref**: Val**; Version1.1.0
kibuzzard-63D0D5A9: G***; kibuzzard-63D0D5A9
kibuzzard-63D0D5D8: G***; kibuzzard-63D0D5D8
kibuzzard-63D0D6BF: G***; kibuzzard-63D0D6BF
kibuzzard-63D0D6CA: G***; kibuzzard-63D0D6CA
kibuzzard-63D0D7E7: G***; kibuzzard-63D0D7E7
kibuzzard-63D0D78E: G***; kibuzzard-63D0D78E
kibuzzard-63D0D81B: G***; kibuzzard-63D0D81B
kibuzzard-63D0D88E: G***; kibuzzard-63D0D88E
kibuzzard-63D0DB6C: G***; kibuzzard-63D0DB6C
kibuzzard-63D0DB7A: G***; kibuzzard-63D0DB7A
kibuzzard-63D0DB98: G***; kibuzzard-63D0DB98
kibuzzard-63D0DBA8: G***; kibuzzard-63D0DBA8
kibuzzard-63D0DBC0: G***; kibuzzard-63D0DBC0
kibuzzard-63D0DBF0, kibuzzard-63D0DBF0#2: G***; kibuzzard-63D0DBF0
kibuzzard-63DB5B79: G***; kibuzzard-63DB5B79
kibuzzard-63DB5C1A: G***; kibuzzard-63DB5C1A
kibuzzard-63DB5C2A, kibuzzard-63DB5C2A#2: G***; kibuzzard-63DB5C2A
kibuzzard-63DB5CBE: G***; kibuzzard-63DB5CBE
kibuzzard-63DB5CD0: G***; kibuzzard-63DB5CD0
kibuzzard-63DB9B0F: G***; kibuzzard-63DB9B0F
kibuzzard-63DB9B4A: G***; kibuzzard-63DB9B4A
kibuzzard-63DB9B6F: G***; kibuzzard-63DB9B6F
kibuzzard-63DB9B22: G***; kibuzzard-63DB9B22
kibuzzard-63DB9B39: G***; kibuzzard-63DB9B39
kibuzzard-63DB9B82: G***; kibuzzard-63DB9B82
kibuzzard-63DB9B95: G***; kibuzzard-63DB9B95
kibuzzard-63DB9BB2: G***; kibuzzard-63DB9BB2
kibuzzard-63DB9BBC: G***; kibuzzard-63DB9BBC
kibuzzard-63DB9BC7: G***; kibuzzard-63DB9BC7
kibuzzard-63DB9BD1: G***; kibuzzard-63DB9BD1
kibuzzard-63DB9BDF: G***; kibuzzard-63DB9BDF
kibuzzard-63DB9BEA: G***; kibuzzard-63DB9BEA
kibuzzard-63DB9BF5: G***; kibuzzard-63DB9BF5
kibuzzard-63DB9C3D: G***; kibuzzard-63DB9C3D
kibuzzard-63DB9C05: G***; kibuzzard-63DB9C05
kibuzzard-63DB9C5F: G***; kibuzzard-63DB9C5F
kibuzzard-63DB9C6A: G***; kibuzzard-63DB9C6A
kibuzzard-63DB9C8D: G***; kibuzzard-63DB9C8D
kibuzzard-63DB9C18: G***; kibuzzard-63DB9C18
kibuzzard-63DB9C25: G***; kibuzzard-63DB9C25
kibuzzard-63DB9C31: G***; kibuzzard-63DB9C31
kibuzzard-63DB9C47: G***; kibuzzard-63DB9C47
kibuzzard-63DB9C52: G***; kibuzzard-63DB9C52
kibuzzard-63DB9C76: G***; kibuzzard-63DB9C76
kibuzzard-63DB9C82: G***; kibuzzard-63DB9C82
kibuzzard-63DB9C97: G***; kibuzzard-63DB9C97
kibuzzard-63DB9CA2: G***; kibuzzard-63DB9CA2
kibuzzard-63DB9CAE: G***; kibuzzard-63DB9CAE
kibuzzard-63DB9D1E: G***; kibuzzard-63DB9D1E
kibuzzard-63DB9D4E: G***; kibuzzard-63DB9D4E
kibuzzard-63DB9D5B: G***; kibuzzard-63DB9D5B
kibuzzard-63DB9D9C: G***; kibuzzard-63DB9D9C
kibuzzard-63DB9D42: G***; kibuzzard-63DB9D42
kibuzzard-63DB9D68: G***; kibuzzard-63DB9D68
kibuzzard-63DB9D76: G***; kibuzzard-63DB9D76
kibuzzard-63DB9D81: G***; kibuzzard-63DB9D81
kibuzzard-63DB9D90: G***; kibuzzard-63DB9D90
kibuzzard-63DB9DA8: G***; kibuzzard-63DB9DA8
kibuzzard-63DB9DB6: G***; kibuzzard-63DB9DB6
kibuzzard-63DB9DC9: G***; kibuzzard-63DB9DC9
kibuzzard-63DB9DD3: G***; kibuzzard-63DB9DD3
kibuzzard-63DB9DE3: G***; kibuzzard-63DB9DE3
kibuzzard-63DB9DF0: G***; kibuzzard-63DB9DF0
kibuzzard-63DB9E4D: G***; kibuzzard-63DB9E4D
kibuzzard-63DB9E5A: G***; kibuzzard-63DB9E5A
kibuzzard-63DB9E8E: G***; kibuzzard-63DB9E8E
kibuzzard-63DB9E9A: G***; kibuzzard-63DB9E9A
kibuzzard-63DB9E16: G***; kibuzzard-63DB9E16
kibuzzard-63DB9E22: G***; kibuzzard-63DB9E22
kibuzzard-63DB9E42: G***; kibuzzard-63DB9E42
kibuzzard-63DB9E68: G***; kibuzzard-63DB9E68
kibuzzard-63DB9E75: G***; kibuzzard-63DB9E75
kibuzzard-63DB9E80: G***; kibuzzard-63DB9E80
kibuzzard-63DB9EA7: G***; kibuzzard-63DB9EA7
kibuzzard-63DB9EB7: G***; kibuzzard-63DB9EB7
kibuzzard-63DB9EC3: G***; kibuzzard-63DB9EC3
kibuzzard-63DB9ED0: G***; kibuzzard-63DB9ED0
kibuzzard-63DB9EDD: G***; kibuzzard-63DB9EDD
kibuzzard-63DB9EE9: G***; kibuzzard-63DB9EE9
kibuzzard-63DB9F7D: G***; kibuzzard-63DB9F7D
kibuzzard-63DB9F8B: G***; kibuzzard-63DB9F8B
kibuzzard-63DB9F37: G***; kibuzzard-63DB9F37
kibuzzard-63DB9F59: G***; kibuzzard-63DB9F59
kibuzzard-63DB9F65: G***; kibuzzard-63DB9F65
kibuzzard-63DB9F70: G***; kibuzzard-63DB9F70
kibuzzard-63DB9FAF: G***; kibuzzard-63DB9FAF
kibuzzard-63DB9FB8: G***; kibuzzard-63DB9FB8
kibuzzard-63DB9FC0: G***; kibuzzard-63DB9FC0
kibuzzard-63DB9FC8: G***; kibuzzard-63DB9FC8
kibuzzard-63DB9FD5: G***; kibuzzard-63DB9FD5
kibuzzard-63DB9FE4: G***; kibuzzard-63DB9FE4
kibuzzard-63DB9FEE: G***; kibuzzard-63DB9FEE
kibuzzard-63DB5956: G***; kibuzzard-63DB5956
kibuzzard-63DBA0A5: G***; kibuzzard-63DBA0A5
kibuzzard-63DBA0B0: G***; kibuzzard-63DBA0B0
kibuzzard-63DBA0B9: G***; kibuzzard-63DBA0B9
kibuzzard-63DBA1AD: G***; kibuzzard-63DBA1AD
kibuzzard-63DBA1B8: G***; kibuzzard-63DBA1B8
kibuzzard-63DBA1C2: G***; kibuzzard-63DBA1C2
kibuzzard-63DBA1CC: G***; kibuzzard-63DBA1CC
kibuzzard-63DBA1D6: G***; kibuzzard-63DBA1D6
kibuzzard-63DBA1E0: G***; kibuzzard-63DBA1E0
kibuzzard-63DBA1EC: G***; kibuzzard-63DBA1EC
kibuzzard-63DBA1FB: G***; kibuzzard-63DBA1FB
kibuzzard-63DBA2A7: G***; kibuzzard-63DBA2A7
kibuzzard-63DBA2AF: G***; kibuzzard-63DBA2AF
kibuzzard-63DBA2B9: G***; kibuzzard-63DBA2B9
kibuzzard-63DBA2C2: G***; kibuzzard-63DBA2C2
kibuzzard-63DBA2CC: G***; kibuzzard-63DBA2CC
kibuzzard-63DBA02D: G***; kibuzzard-63DBA02D
kibuzzard-63DBA2D7: G***; kibuzzard-63DBA2D7
kibuzzard-63DBA2FF: G***; kibuzzard-63DBA2FF
kibuzzard-63DBA04D: G***; kibuzzard-63DBA04D
kibuzzard-63DBA5C2: G***; kibuzzard-63DBA5C2
kibuzzard-63DBA06B: G***; kibuzzard-63DBA06B
kibuzzard-63DBA07D: G***; kibuzzard-63DBA07D
kibuzzard-63DBA08C: G***; kibuzzard-63DBA08C
kibuzzard-63DBA09E: G***; kibuzzard-63DBA09E
kibuzzard-63DBA011: G***; kibuzzard-63DBA011
kibuzzard-63DBA14D: G***; kibuzzard-63DBA14D
kibuzzard-63DBA17F: G***; kibuzzard-63DBA17F
kibuzzard-63DBA18A: G***; kibuzzard-63DBA18A
kibuzzard-63DBA019: G***; kibuzzard-63DBA019
kibuzzard-63DBA024: G***; kibuzzard-63DBA024
kibuzzard-63DBA25A: G***; kibuzzard-63DBA25A
kibuzzard-63DBA28C: G***; kibuzzard-63DBA28C
kibuzzard-63DBA29D: G***; kibuzzard-63DBA29D
kibuzzard-63DBA31E: G***; kibuzzard-63DBA31E
kibuzzard-63DBA33C: G***; kibuzzard-63DBA33C
kibuzzard-63DBA35B: G***; kibuzzard-63DBA35B
kibuzzard-63DBA038: G***; kibuzzard-63DBA038
kibuzzard-63DBA043: G***; kibuzzard-63DBA043
kibuzzard-63DBA056: G***; kibuzzard-63DBA056
kibuzzard-63DBA060: G***; kibuzzard-63DBA060
kibuzzard-63DBA60B: G***; kibuzzard-63DBA60B
kibuzzard-63DBA075: G***; kibuzzard-63DBA075
kibuzzard-63DBA085: G***; kibuzzard-63DBA085
kibuzzard-63DBA093: G***; kibuzzard-63DBA093
kibuzzard-63DBA106: G***; kibuzzard-63DBA106
kibuzzard-63DBA110: G***; kibuzzard-63DBA110
kibuzzard-63DBA157: G***; kibuzzard-63DBA157
kibuzzard-63DBA240: G***; kibuzzard-63DBA240
kibuzzard-63DBA264: G***; kibuzzard-63DBA264
kibuzzard-63DBA270: G***; kibuzzard-63DBA270
kibuzzard-63DBA279: G***; kibuzzard-63DBA279
kibuzzard-63DBA282: G***; kibuzzard-63DBA282
kibuzzard-63DBA295: G***; kibuzzard-63DBA295
kibuzzard-63DBA308: G***; kibuzzard-63DBA308
kibuzzard-63DBA315: G***; kibuzzard-63DBA315
kibuzzard-63DBA329: G***; kibuzzard-63DBA329
kibuzzard-63DBA332: G***; kibuzzard-63DBA332
kibuzzard-63DBA346: G***; kibuzzard-63DBA346
kibuzzard-63DBA352: G***; kibuzzard-63DBA352
kibuzzard-63DBA366: G***; kibuzzard-63DBA366
kibuzzard-63DBA594: G***; kibuzzard-63DBA594
kibuzzard-63DBA652: G***; kibuzzard-63DBA652
kibuzzard-63DBA679: G***; kibuzzard-63DBA679
kibuzzard-64B794A8, kibuzzard-64B794A8#2: G***; kibuzzard-64B794A8
kibuzzard-64B794B0, kibuzzard-64B794B0#2: G***; kibuzzard-64B794B0
kibuzzard-64B794BC, kibuzzard-64B794BC#2: G***; kibuzzard-64B794BC
kibuzzard-64B794C8, kibuzzard-64B794C8#2: G***; kibuzzard-64B794C8
kibuzzard-64B794D8, kibuzzard-64B794D8#2: G***; kibuzzard-64B794D8
kibuzzard-64B794E2, kibuzzard-64B794E2#2: G***; kibuzzard-64B794E2
kibuzzard-64B794F0, kibuzzard-64B794F0#2: G***; kibuzzard-64B794F0
kibuzzard-64B794FA, kibuzzard-64B794FA#2: G***; kibuzzard-64B794FA
kibuzzard-64B7949A, kibuzzard-64B7949A#2: G***; kibuzzard-64B7949A
kibuzzard-64B7950D, kibuzzard-64B7950D#2: G***; kibuzzard-64B7950D
kibuzzard-64B7951A, kibuzzard-64B7951A#2: G***; kibuzzard-64B7951A
kibuzzard-64B7952A, kibuzzard-64B7952A#2: G***; kibuzzard-64B7952A
kibuzzard-64B7953B, kibuzzard-64B7953B#2: G***; kibuzzard-64B7953B
kibuzzard-64B79148: G***; kibuzzard-64B79148
kibuzzard-64B79150: G***; kibuzzard-64B79150
kibuzzard-64B79501, kibuzzard-64B79501#2: G***; kibuzzard-64B79501
kibuzzard-64B79524, kibuzzard-64B79524#2: G***; kibuzzard-64B79524
kibuzzard-64B79532, kibuzzard-64B79532#2: G***; kibuzzard-64B79532
kibuzzard-64D5E88C: G***; kibuzzard-64D5E88C
kibuzzard-64736A4E, kibuzzard-64736A4E#2: G***; kibuzzard-64736A4E
kibuzzard-64736A30, kibuzzard-64736A30#2: G***; kibuzzard-64736A30
kibuzzard-64736B29, kibuzzard-64736B29#2: G***; kibuzzard-64736B29
kibuzzard-64736B32, kibuzzard-64736B32#2: G***; kibuzzard-64736B32
kibuzzard-64736DE1: G***; kibuzzard-64736DE1
kibuzzard-647344B7: G***; kibuzzard-647344B7
kibuzzard-6473446E: G***; kibuzzard-6473446E
kibuzzard-6473447C: G***; kibuzzard-6473447C
kibuzzard-6473450E: G***; kibuzzard-6473450E
kibuzzard-6473451D: G***; kibuzzard-6473451D
kibuzzard-6473453E: G***; kibuzzard-6473453E
kibuzzard-6473454B: G***; kibuzzard-6473454B
kibuzzard-6473467D: G***; kibuzzard-6473467D
kibuzzard-6473468F: G***; kibuzzard-6473468F
kibuzzard-64734485: G***; kibuzzard-64734485
kibuzzard-64734490: G***; kibuzzard-64734490
kibuzzard-64734502: G***; kibuzzard-64734502
kibuzzard-64734552: G***; kibuzzard-64734552
kibuzzard-64734662: G***; kibuzzard-64734662
kibuzzard-64734674: G***; kibuzzard-64734674
kibuzzard-64734686: G***; kibuzzard-64734686
